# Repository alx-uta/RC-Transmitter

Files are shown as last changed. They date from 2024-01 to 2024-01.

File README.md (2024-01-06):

# RC-Transmitter
This is a custom RC Transmitter that's using ESP32 and Semtech SX1280

Authors:
- Marian Uta
- Alex Heisler

# Project Status - WIP
- [https://microknot.dev/rc-transmitter-project-status/](https://microknot.dev/rc-transmitter-project-status/)

---

# Useful links
- [Build Tutorial](https://microknot.dev/rc-transmitter-build-tutorial-esp32-sx1280/)
- [Wiring Tutorial](https://microknot.dev/rc-transmitter-wiring-tutorial-esp32-sx1280/)
- [Calibration Tutorial](https://microknot.dev/rc-transmitter-calibration-tutorial/)

---

- Required Parts:
  - [3D Files](https://docs.google.com/spreadsheets/d/1K6EamDLu7aNF5GFfuzi9vV8SCz_6HzOA_h1CgVDcLqo/edit?usp=sharing)
  - [PCB](https://docs.google.com/spreadsheets/d/1bTyJoKmJrHec9gnfRhsfcdIJgJ4cUt9kbDGZgcYngUU/edit?usp=sharing)
  - [BOM](https://docs.google.com/spreadsheets/d/1osKjM83mz0m_O5QN-AISYl1IssTSeUwu/edit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)

---
Links:
- [Discord](https://discord.gg/eHyz2aJ6)

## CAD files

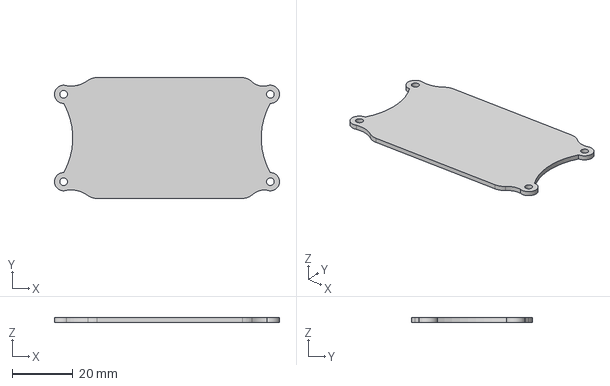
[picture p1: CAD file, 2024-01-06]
3D/CNC_Files/ScreenProtector.step
74.0 x 39.8 x 1.50 mm

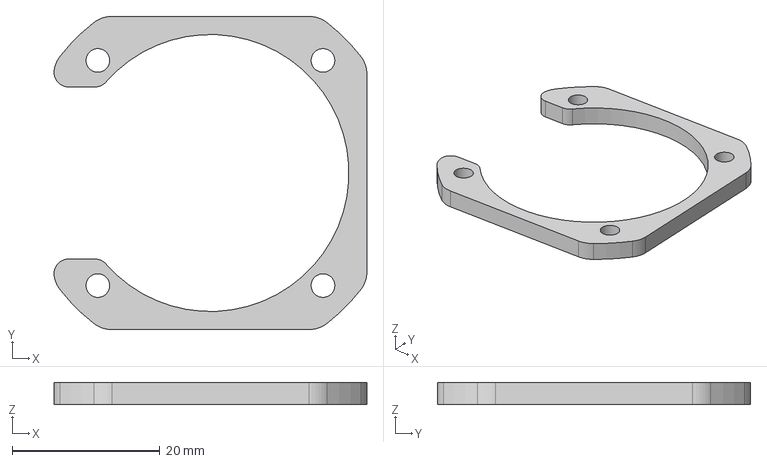
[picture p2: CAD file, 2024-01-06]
3D/STEP/Generic/RotaryEncoderSpacer.step
42.4 x 42.4 x 3.00 mm

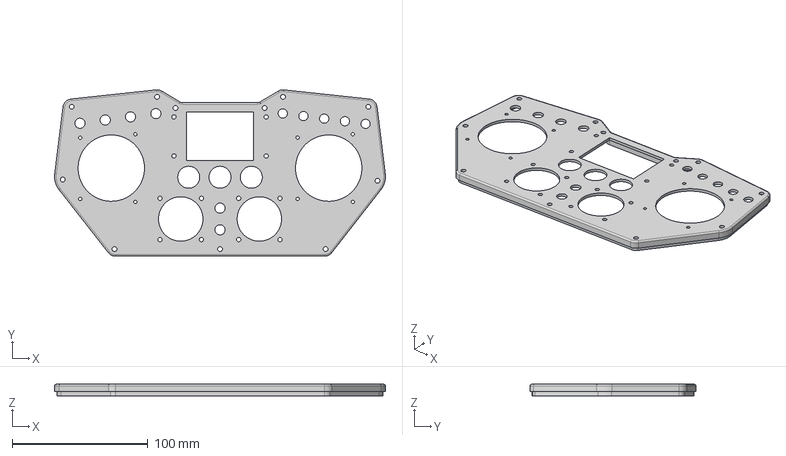
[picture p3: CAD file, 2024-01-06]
3D/STEP/MainBody/Top_Joysticks_AG01.step
244.2 x 122.8 x 8.50 mm

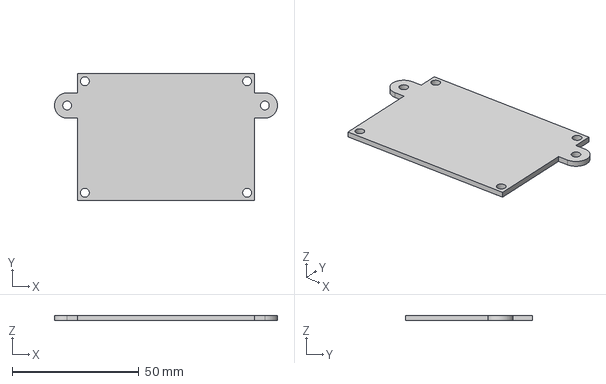
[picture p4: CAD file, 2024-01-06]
3D/STEP/PCB/PCB_Holder.step
88.0 x 50.0 x 2.00 mm

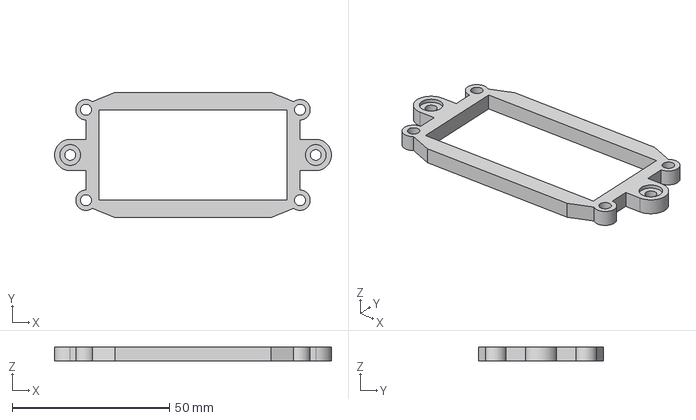
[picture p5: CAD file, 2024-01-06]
3D/STEP/Screen/ScreenHolder.step
88.0 x 39.8 x 4.50 mm

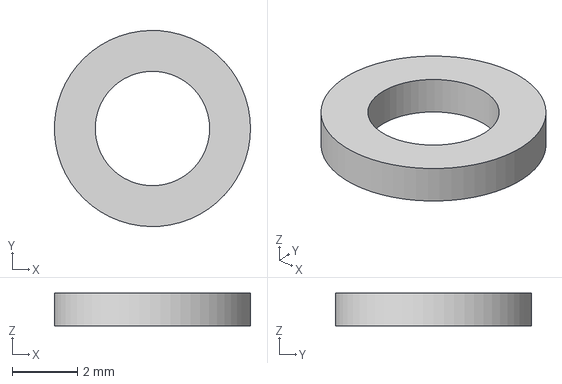
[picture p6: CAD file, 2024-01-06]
3D/STEP/Generic/Spacer.step
6.00 x 6.00 x 1.00 mm

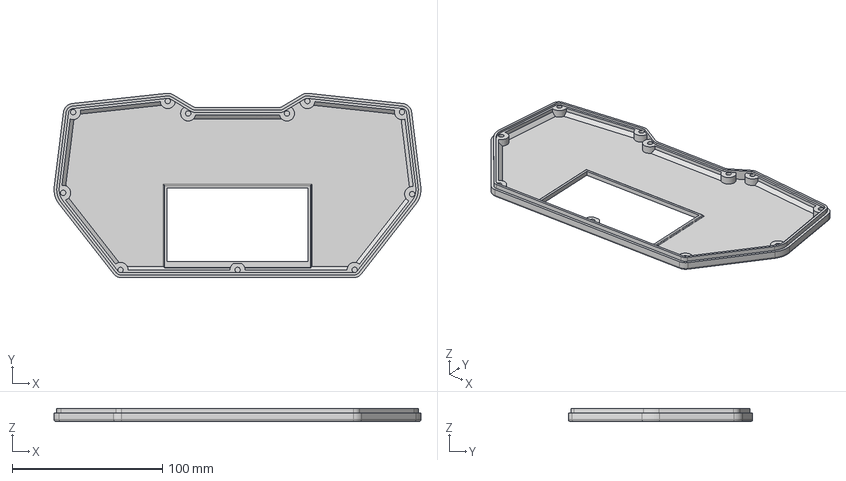
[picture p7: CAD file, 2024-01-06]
3D/STEP/MainBody/Bottom.step
244.2 x 122.8 x 8.50 mm

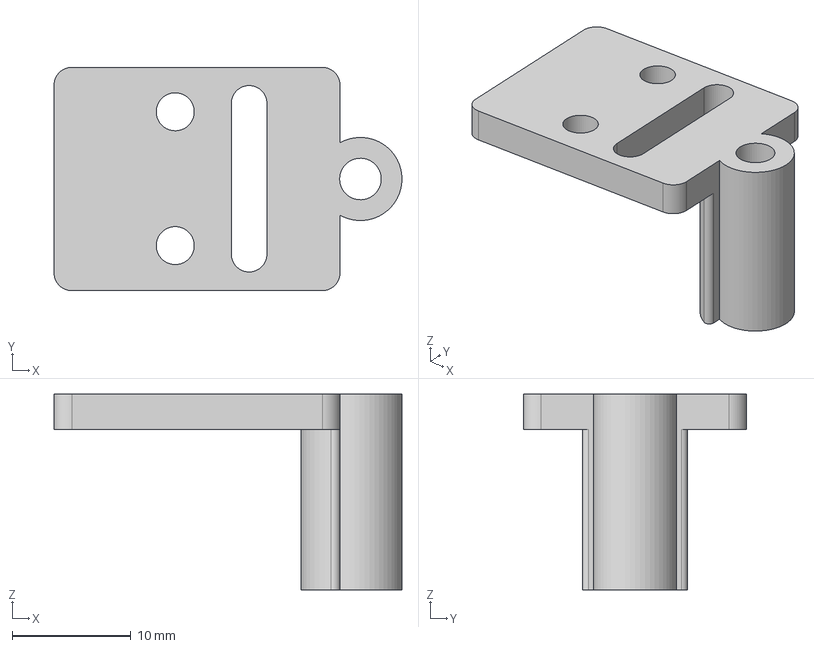
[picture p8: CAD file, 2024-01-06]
3D/STEP/PCB/JoystickAdapterHolder.step
29.3 x 18.8 x 16.5 mm

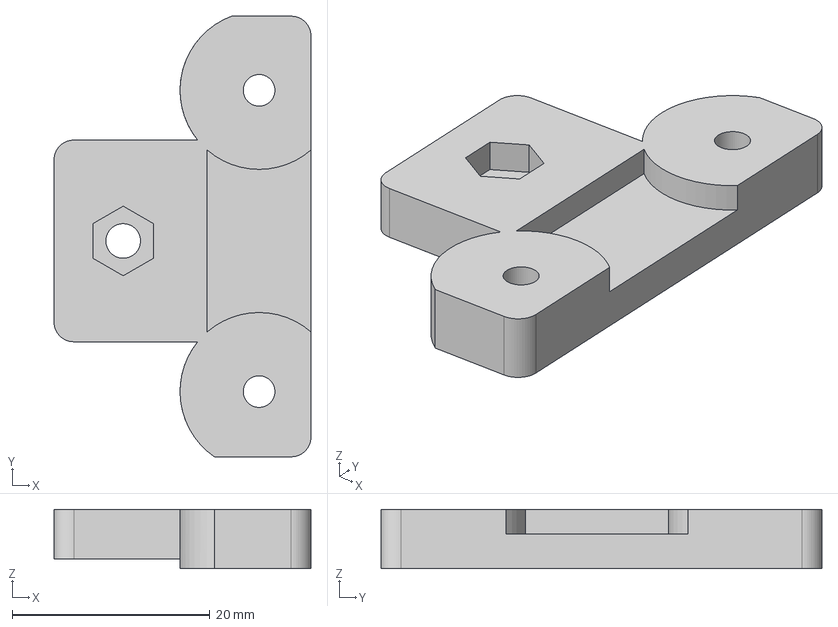
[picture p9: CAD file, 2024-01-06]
3D/STEP/Battery/BatteryHolderConnector.step
26.0 x 44.6 x 6.00 mm

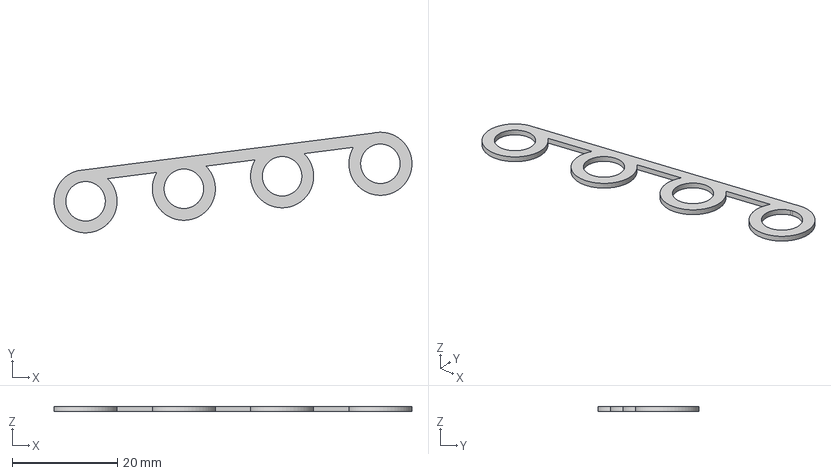
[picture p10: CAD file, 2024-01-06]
3D/STEP/Generic/PotentiometersHolder_4.step
68.0 x 19.1 x 1.00 mm

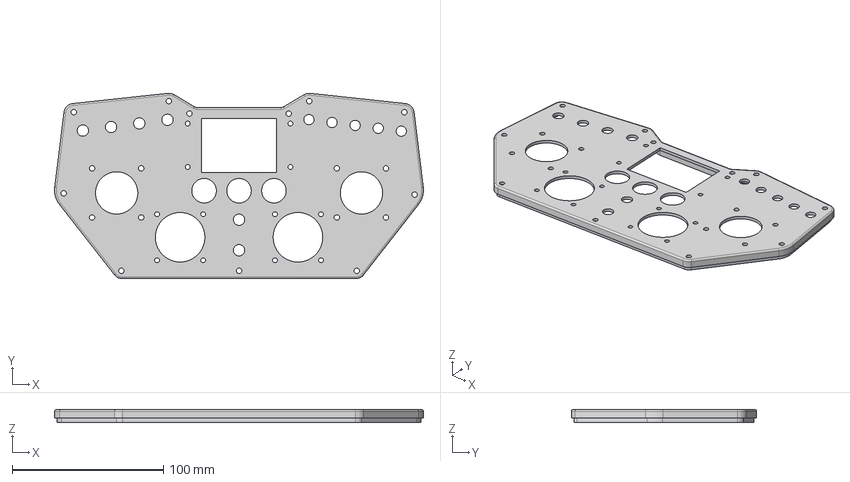
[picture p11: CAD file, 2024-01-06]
3D/STEP/MainBody/Top_Joysticks_JH-D202X.step
244.2 x 122.8 x 8.50 mm

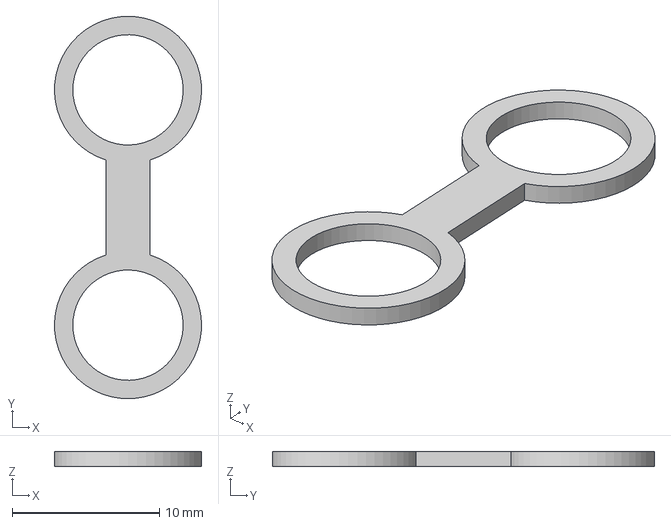
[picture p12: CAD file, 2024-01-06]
3D/STEP/Generic/PotentiometersHolder_2.step
9.99 x 26.0 x 1.00 mm

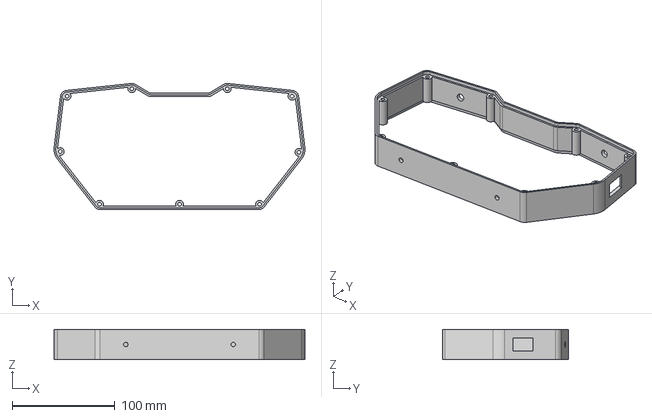
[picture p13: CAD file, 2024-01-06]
3D/STEP/MainBody/Middle.step
244.2 x 122.8 x 29.5 mm

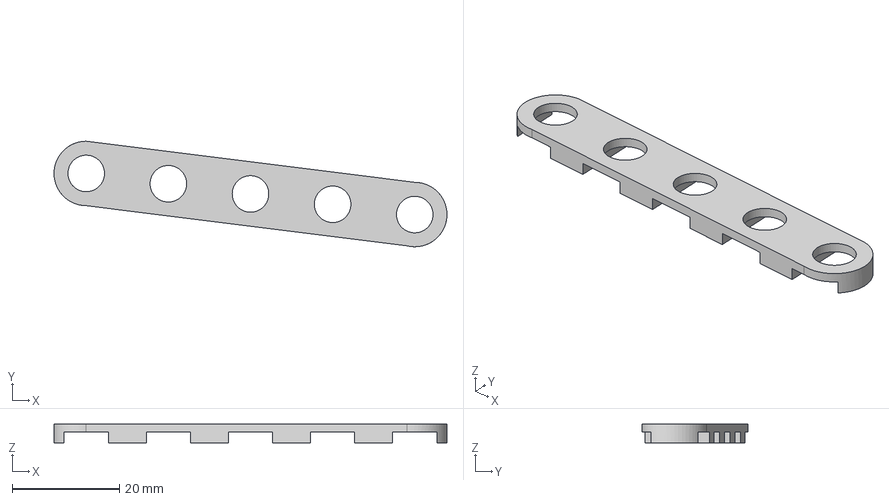
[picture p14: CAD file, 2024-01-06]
3D/STEP/Generic/SwitchesHolder.step
73.1 x 19.7 x 3.50 mm

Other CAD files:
3D/STEP/Battery/BatteryCover.step
3D/STEP/Battery/21700_BatteryHolder.step
3D/STEP/Battery/18650_BatteryHolderSpacer.step
3D/STEP/Battery/18650_BatteryHolder.step
3D/STEP/Battery/21700_BatteryHolderSpacer.step
3D/STL/Battery/18650_BatteryHolder.stl
3D/STL/Battery/18650_BatteryHolderSpacer.stl
3D/STL/Battery/21700_BatteryHolder.stl
3D/STL/Battery/21700_BatteryHolderSpacer.stl
3D/STL/Battery/BatteryCover.stl
3D/STL/Battery/BatteryHolderConnector.stl
3D/STL/Generic/PotentiometersHolder_2.stl
3D/STL/Generic/PotentiometersHolder_4.stl
3D/STL/Generic/RotaryEncoderSpacer.stl
3D/STL/Generic/Spacer.stl
3D/STL/Generic/SwitchesHolder.stl
3D/STL/MainBody/Bottom.stl
3D/STL/MainBody/Middle.stl
3D/STL/MainBody/Top_Joysticks_AG01.stl
3D/STL/MainBody/Top_Joysticks_JH-D202X.stl
3D/STL/PCB/JoystickAdapterHolder.stl
3D/STL/PCB/PCB_Holder.stl
3D/STL/Screen/ScreenHolder.stl

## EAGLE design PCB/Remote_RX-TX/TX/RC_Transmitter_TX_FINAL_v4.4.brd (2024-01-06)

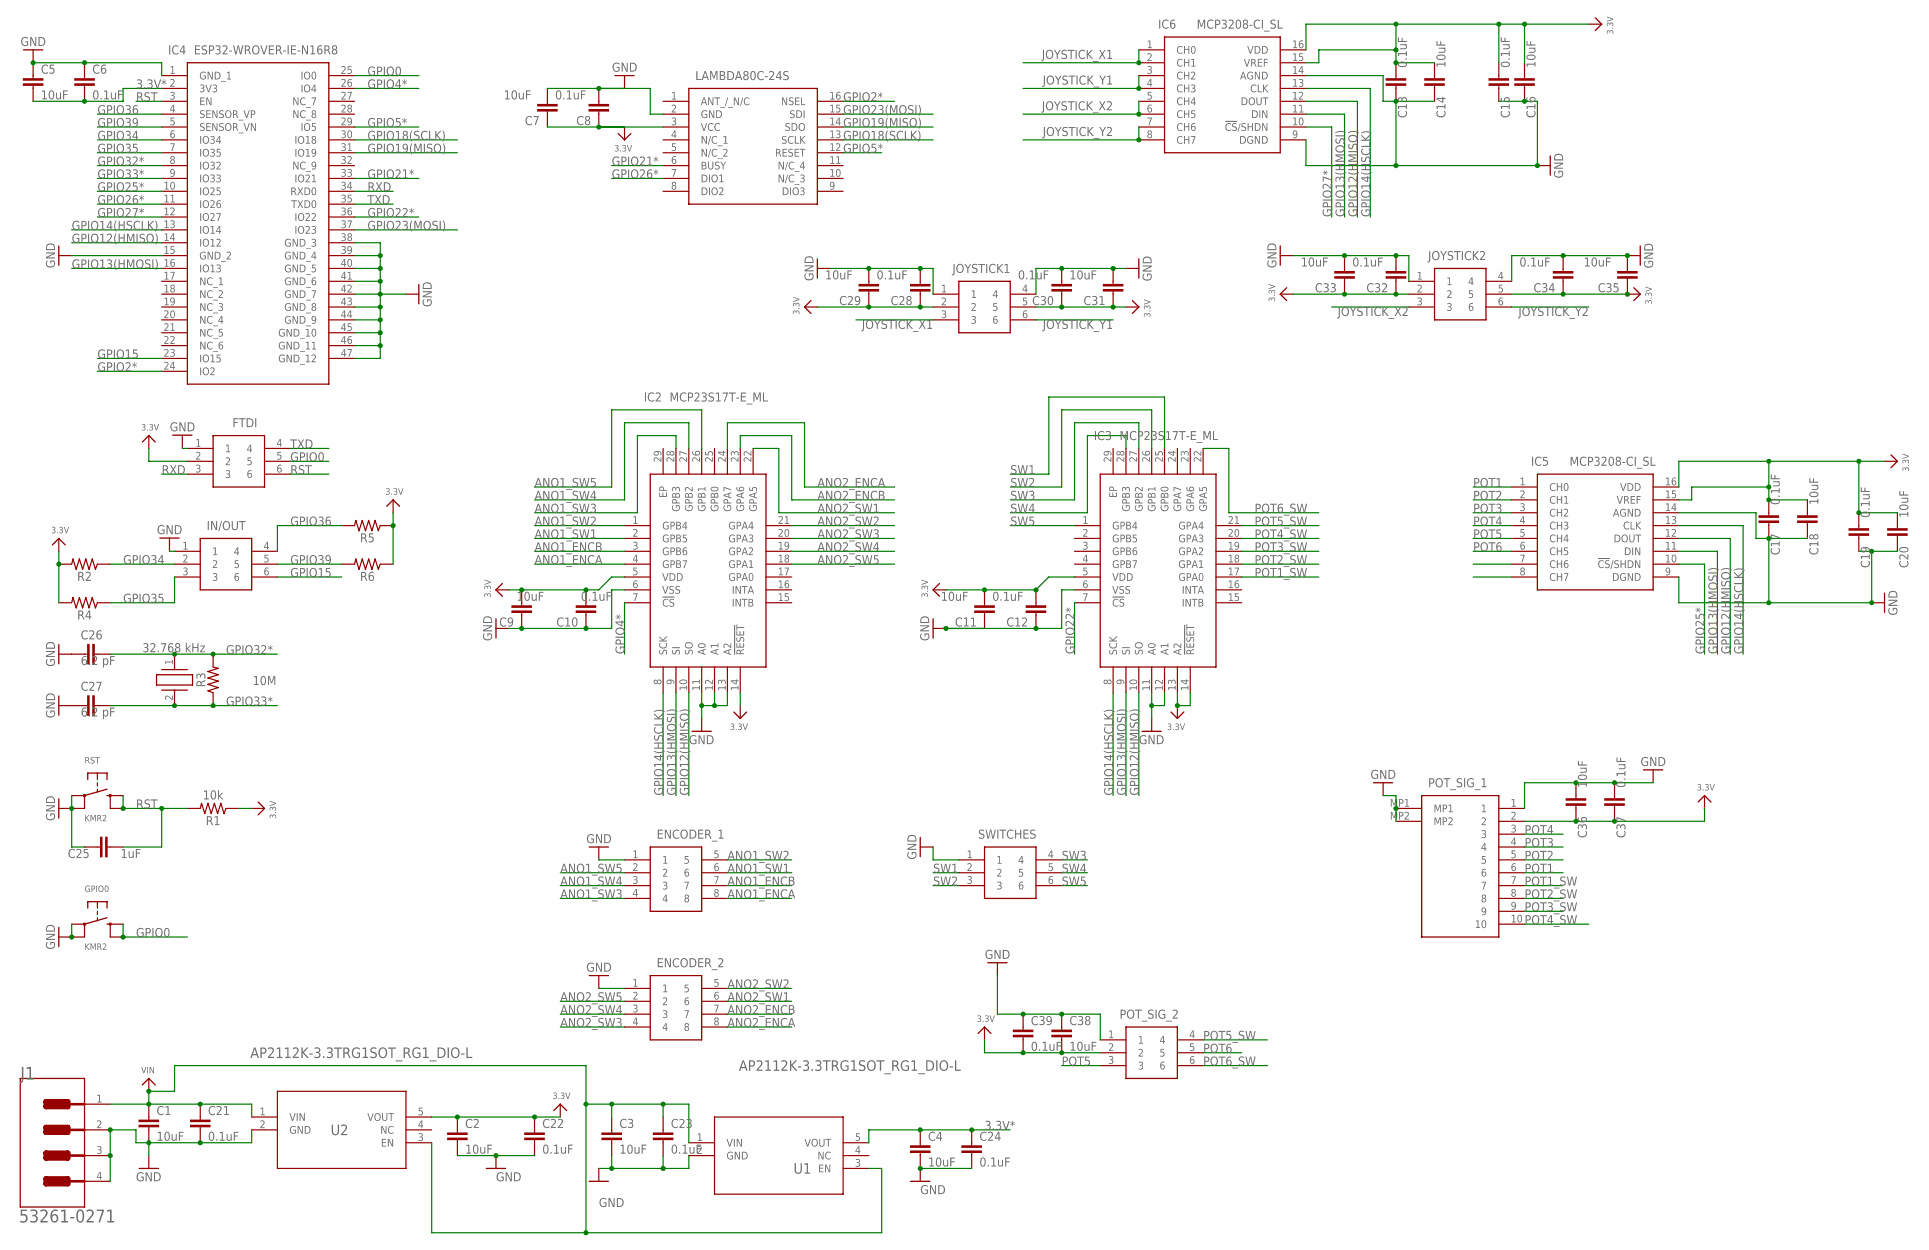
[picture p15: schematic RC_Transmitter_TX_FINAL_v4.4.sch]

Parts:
C1, C2, C3, C4, C5, C7, C9, C11, C14, C16, C18, C20, C29, C31, C33, C35, C36, C38: 10uF; 0805
C6, C8, C10, C12, C13, C15, C17, C19, C21, C22, C23, C24, C28, C30, C32, C34, C37, C39: 0.1uF; 0805
C25: 1uF; 0805
C26, C27: 6.2 pF; 0805
CRYSTAL: 32.768 kHz; ECX327CDX1293
ENCODER_1, ENCODER_2: 0532610871; 53261-0871
FTDI: 0532610671
GPIO0: KMR2; BTN_KMR2_4.6X2.8
IC1: LAMBDA80C-24S; LAMBDA80C24S
IC2, IC3: MCP23S17T-E_ML; QFN65P600X600X100-29N
IC4: ESP32-WROVER-IE-N16R8; ESP32WROVERIEN16R8
IC5, IC6: MCP3208-CI_SL; SOIC127P600X175-16N
IN/OUT: 0532610671
J1: MOLEX_53261-0271MOLEX_53261-0271_0_0; MOLEX_53261-0271_0
JOYSTICK1, JOYSTICK2: 0532610671
POT_SIG_1: 0532611071
POT_SIG_2: 0532610671
R1, R2, R4, R5, R6: 10k; 0603
R3: 10M; 0603
RST: KMR2; BTN_KMR2_4.6X2.8
SWITCHES: 0532610671
U1, U2: AP2112K-3.3TRG1SOT_RG1_DIO-L; SOT_RG1_DIO-L

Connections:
3.3V: C2.1, C7.1, C8.1, C9.2, C10.2, C11.2, C12.2, C13.2, C14.2, C15.2, C16.2, C17.2, C18.2, C19.2, C20.2, C22.1, C28.1, C29.1, C30.1, C31.1, C32.1, C33.1, C34.1, C35.1, C36.1, C37.1, C38.2, C39.2, FTDI.2, IC1.3 (VCC), IC2.5 (VDD), IC2.14 (!RESET), IC3.5 (VDD), IC3.13 (A2), IC3.14 (!RESET), IC5.15 (VREF), IC5.16 (VDD), IC6.15 (VREF), IC6.16 (VDD), JOYSTICK1.2, JOYSTICK1.5, JOYSTICK2.2, JOYSTICK2.5, POT_SIG_1.2, POT_SIG_2.2, R1.1, R2.2, R4.2, R5.1, R6.1, U2.5 (VOUT)
3.3V*: C4.1, C5.2, C6.2, C24.1, IC4.2 (3V3), U1.5 (VOUT)
ANO1_ENCA: ENCODER_1.8, IC2.4 (GPB7)
ANO1_ENCB: ENCODER_1.7, IC2.3 (GPB6)
ANO1_SW1: ENCODER_1.6, IC2.2 (GPB5)
ANO1_SW2: ENCODER_1.5, IC2.1 (GPB4)
ANO1_SW3: ENCODER_1.4, IC2.28 (GPB3)
ANO1_SW4: ENCODER_1.3, IC2.27 (GPB2)
ANO1_SW5: ENCODER_1.2, IC2.26 (GPB1)
ANO2_ENCA: ENCODER_2.8, IC2.24 (GPA7)
ANO2_ENCB: ENCODER_2.7, IC2.23 (GPA6)
ANO2_SW1: ENCODER_2.6, IC2.22 (GPA5)
ANO2_SW2: ENCODER_2.5, IC2.21 (GPA4)
ANO2_SW3: ENCODER_2.4, IC2.20 (GPA3)
ANO2_SW4: ENCODER_2.3, IC2.19 (GPA2)
ANO2_SW5: ENCODER_2.2, IC2.18 (GPA1)
GND: C1.2, C2.2, C3.2, C4.2, C5.1, C6.1, C7.2, C8.2, C9.1, C10.1, C11.1, C12.1, C13.1, C14.1, C15.1, C16.1, C17.1, C18.1, C19.1, C20.1, C21.2, C22.2, C23.2, C24.2, C25.1, C26.1, C27.1, C28.2, C29.2, C30.2, C31.2, C32.2, C33.2, C34.2, C35.2, C36.2, C37.2, C38.1, C39.1, ENCODER_1.1, ENCODER_2.1, FTDI.1, GPIO0.A, GPIO0.A' (P1), IC1.2 (GND), IC2.6 (VSS), IC2.11 (A0), IC2.12 (A1), IC2.13 (A2), IC3.6 (VSS), IC3.11 (A0), IC3.12 (A1), IC4.1 (GND_1), IC4.15 (GND_2), IC4.38 (GND_3), IC4.39 (GND_4), IC4.40 (GND_5), IC4.41 (GND_6), IC4.42 (GND_7), IC4.43 (GND_8), IC4.44 (GND_9), IC4.45 (GND_10), IC4.46 (GND_11), IC4.47 (GND_12), IC5.9 (DGND), IC5.14 (AGND), IC6.9 (DGND), IC6.14 (AGND), IN/OUT.1, J1.2, J1.3 (MNT_1), J1.4 (MNT_2), JOYSTICK1.1, JOYSTICK1.4, JOYSTICK2.1, JOYSTICK2.4, POT_SIG_1.1, POT_SIG_1.MP1, POT_SIG_1.MP2, POT_SIG_2.1, RST.A, RST.A' (P1), SWITCHES.1, U1.2 (GND), U2.2 (GND)
GPIO0: FTDI.5, GPIO0.B (S), GPIO0.B' (S1), IC4.25 (IO0)
GPIO2*: IC1.16 (NSEL), IC4.24 (IO2)
GPIO4*: IC2.7 (!CS), IC4.26 (IO4)
GPIO5*: IC1.12 (RESET), IC4.29 (IO5)
GPIO12(HMISO): IC2.10 (SO), IC3.10 (SO), IC4.14 (IO12), IC5.12 (DOUT), IC6.12 (DOUT)
GPIO13(HMOSI): IC2.9 (SI), IC3.9 (SI), IC4.16 (IO13), IC5.11 (DIN), IC6.11 (DIN)
GPIO14(HSCLK): IC2.8 (SCK), IC3.8 (SCK), IC4.13 (IO14), IC5.13 (CLK), IC6.13 (CLK)
GPIO15: IC4.23 (IO15), IN/OUT.6
GPIO18(SCLK): IC1.13 (SCLK), IC4.30 (IO18)
GPIO19(MISO): IC1.14 (SDO), IC4.31 (IO19)
GPIO21*: IC1.6 (BUSY), IC4.33 (IO21)
GPIO22*: IC3.7 (!CS), IC4.36 (IO22)
GPIO23(MOSI): IC1.15 (SDI), IC4.37 (IO23)
GPIO25*: IC4.10 (IO25), IC5.10 (!CS!/SHDN)
GPIO26*: IC1.7 (DIO1), IC4.11 (IO26)
GPIO27*: IC4.12 (IO27), IC6.10 (!CS!/SHDN)
GPIO32*: C26.2, CRYSTAL.1 (X1), IC4.8 (IO32), R3.2
GPIO33*: C27.2, CRYSTAL.2 (X2), IC4.9 (IO33), R3.1
GPIO34: IC4.6 (IO34), IN/OUT.2, R2.1
GPIO35: IC4.7 (IO35), IN/OUT.3, R4.1
GPIO36: IC4.4 (SENSOR_VP), IN/OUT.4, R5.2
GPIO39: IC4.5 (SENSOR_VN), IN/OUT.5, R6.2
JOYSTICK_X1: IC6.1 (CH0), IC6.2 (CH1), JOYSTICK1.3
JOYSTICK_X2: IC6.5 (CH4), IC6.6 (CH5), JOYSTICK2.3
JOYSTICK_Y1: IC6.3 (CH2), IC6.4 (CH3), JOYSTICK1.6
JOYSTICK_Y2: IC6.7 (CH6), IC6.8 (CH7), JOYSTICK2.6
POT1: IC5.1 (CH0), POT_SIG_1.6
POT1_SW: IC3.17 (GPA0), POT_SIG_1.7
POT2: IC5.2 (CH1), POT_SIG_1.5
POT2_SW: IC3.18 (GPA1), POT_SIG_1.8
POT3: IC5.3 (CH2), POT_SIG_1.4
POT3_SW: IC3.19 (GPA2), POT_SIG_1.9
POT4: IC5.4 (CH3), POT_SIG_1.3
POT4_SW: IC3.20 (GPA3), POT_SIG_1.10
POT5: IC5.5 (CH4), POT_SIG_2.3
POT5_SW: IC3.21 (GPA4), POT_SIG_2.4
POT6: IC5.6 (CH5), POT_SIG_2.5
POT6_SW: IC3.22 (GPA5), POT_SIG_2.6
RST: C25.2, FTDI.6, IC4.3 (EN), R1.2, RST.B (S), RST.B' (S1)
RXD: FTDI.3, IC4.34 (RXD0)
SW1: IC3.25 (GPB0), SWITCHES.2
SW2: IC3.26 (GPB1), SWITCHES.3
SW3: IC3.27 (GPB2), SWITCHES.4
SW4: IC3.28 (GPB3), SWITCHES.5
SW5: IC3.1 (GPB4), SWITCHES.6
TXD: FTDI.4, IC4.35 (TXD0)
VIN: C1.1, C3.1, C21.1, C23.1, J1.1, U1.1 (VIN), U1.3 (EN), U2.1 (VIN), U2.3 (EN)

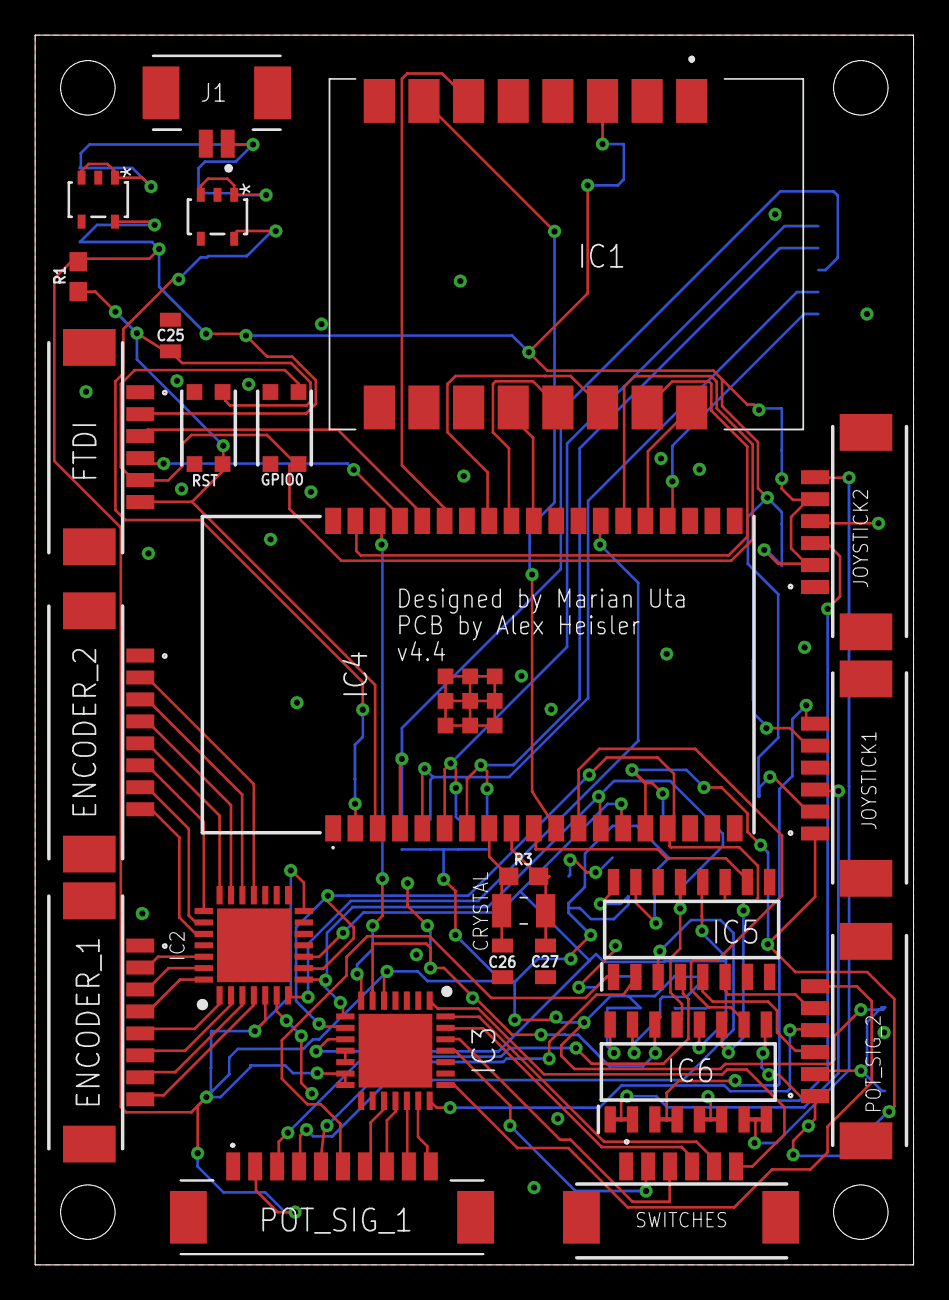
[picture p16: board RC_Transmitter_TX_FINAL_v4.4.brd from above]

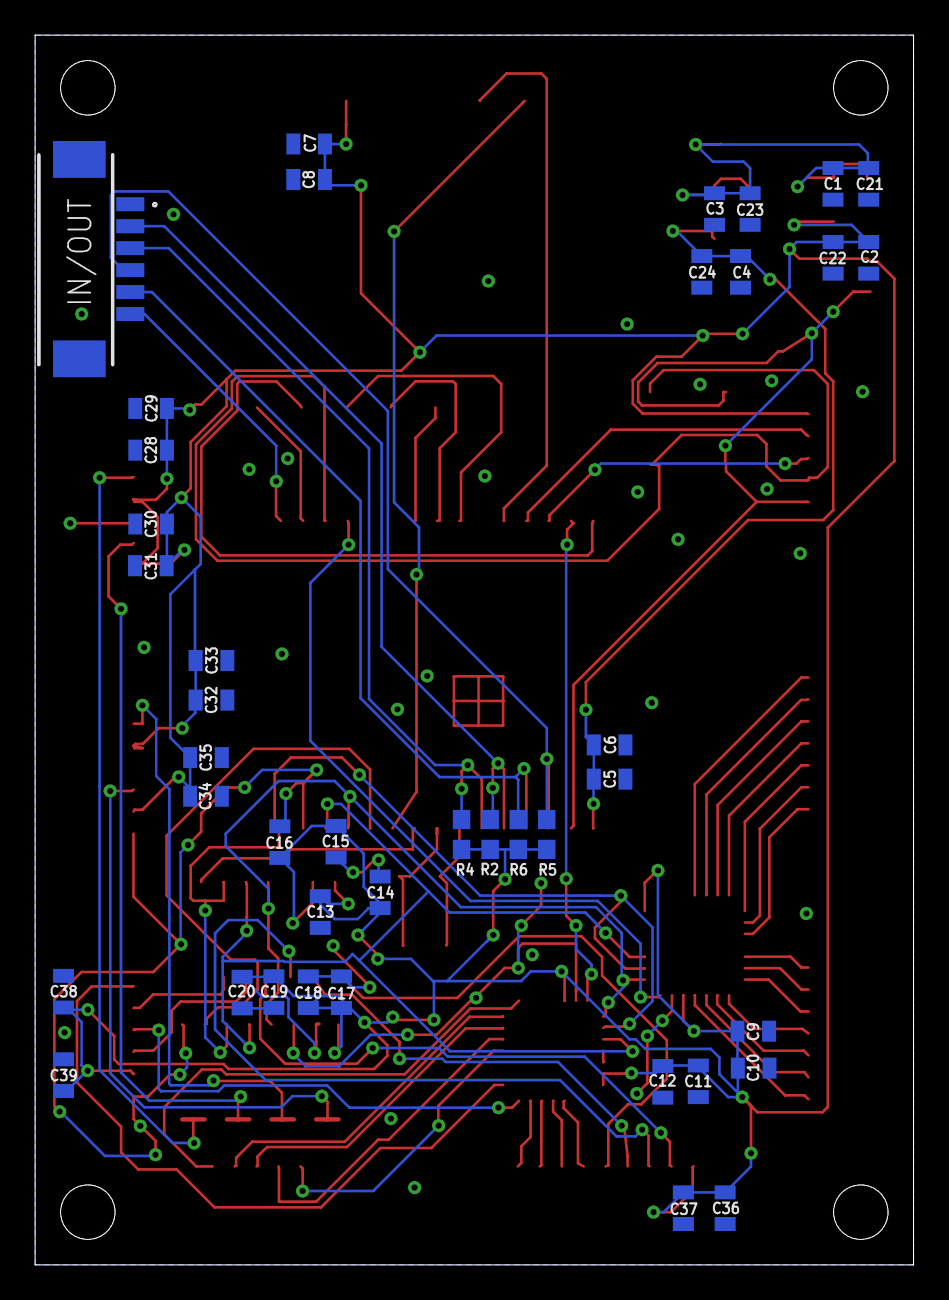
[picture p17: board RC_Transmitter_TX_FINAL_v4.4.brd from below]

Board: 2 copper layers, 50.0 x 70.0 mm, 66 parts (41 on the bottom side), 64 nets.

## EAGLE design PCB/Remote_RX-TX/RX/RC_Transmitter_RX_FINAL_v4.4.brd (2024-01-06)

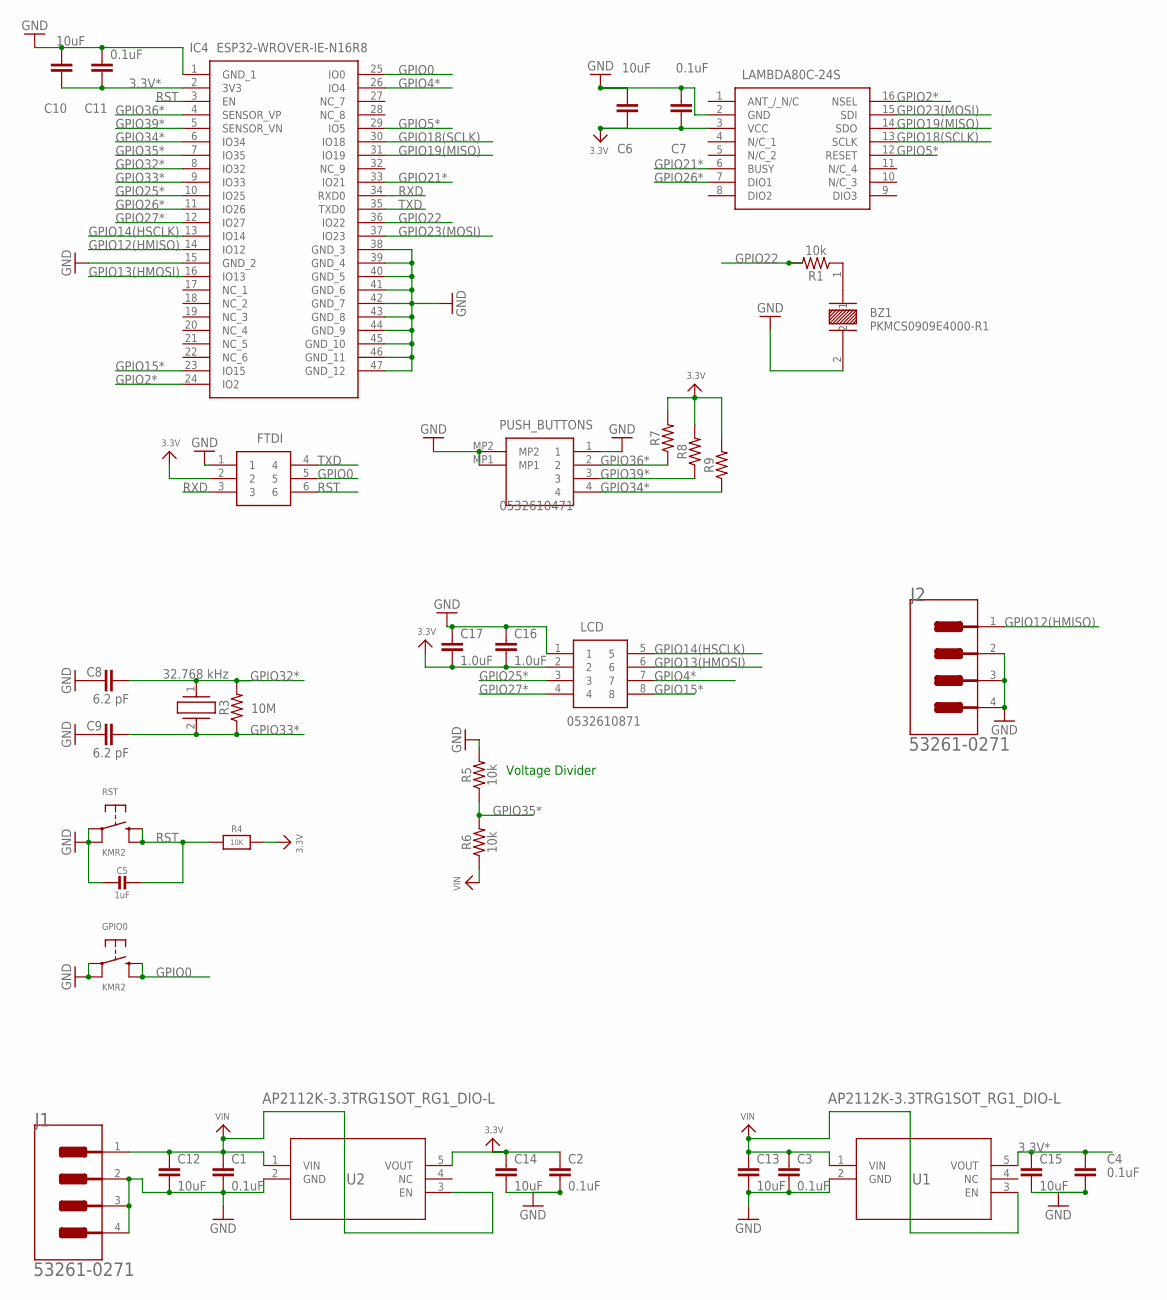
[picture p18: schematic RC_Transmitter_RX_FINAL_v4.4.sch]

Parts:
BZ1: PKMCS0909E4000-R1
C1, C2, C3, C4, C7, C11: 0.1uF; 0805
C5: 1uF; 0805-NO
C6, C10, C12, C13, C14, C15: 10uF; 0805
C8, C9: 6.2 pF; CAPC2012X110
C16, C17: 1.0uF; 0805
CRYSTAL: 32.768 kHz; ECX327CDX1293
FTDI: 0532610671
GPIO0: KMR2; BTN_KMR2_4.6X2.8
IC1: LAMBDA80C-24S; LAMBDA80C24S
IC4: ESP32-WROVER-IE-N16R8; ESP32WROVERIEN16R8
J1, J2: MOLEX_53261-0271MOLEX_53261-0271_0_0; MOLEX_53261-0271_0
LCD: 0532610871; 53261-0871
PUSH_BUTTONS: 0532610471
R1, R5, R6: 10k; 0603
R3: 10M; 0603
R4: 10K; _0805
R7, R8, R9: 0; 0603
RST: KMR2; BTN_KMR2_4.6X2.8
U1, U2: AP2112K-3.3TRG1SOT_RG1_DIO-L; SOT_RG1_DIO-L

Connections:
3.3V: C2.1, C6.1, C7.1, C14.1, C16.2, C17.2, FTDI.2, IC1.3 (VCC), LCD.2, R4.2, R7.2, R8.2, R9.2, U2.5 (VOUT)
3.3V*: C4.1, C10.1, C11.1, C15.1, IC4.2 (3V3), U1.5 (VOUT)
GND: BZ1.2, C1.2, C2.2, C3.2, C4.2, C5.2, C6.2, C7.2, C8.1, C9.1, C10.2, C11.2, C12.2, C13.2, C14.2, C15.2, C16.1, C17.1, FTDI.1, GPIO0.A, GPIO0.A' (P1), IC1.2 (GND), IC4.1 (GND_1), IC4.15 (GND_2), IC4.38 (GND_3), IC4.39 (GND_4), IC4.40 (GND_5), IC4.41 (GND_6), IC4.42 (GND_7), IC4.43 (GND_8), IC4.44 (GND_9), IC4.45 (GND_10), IC4.46 (GND_11), IC4.47 (GND_12), J1.2, J1.3 (MNT_1), J1.4 (MNT_2), J2.2, J2.3 (MNT_1), J2.4 (MNT_2), LCD.1, PUSH_BUTTONS.1, PUSH_BUTTONS.MP1, PUSH_BUTTONS.MP2, R5.2, RST.A, RST.A' (P1), U1.2 (GND), U2.2 (GND)
GPIO0: FTDI.5, GPIO0.B (S), GPIO0.B' (S1), IC4.25 (IO0)
GPIO2*: IC1.16 (NSEL), IC4.24 (IO2)
GPIO4*: IC4.26 (IO4), LCD.7
GPIO5*: IC1.12 (RESET), IC4.29 (IO5)
GPIO12(HMISO): IC4.14 (IO12), J2.1
GPIO13(HMOSI): IC4.16 (IO13), LCD.6
GPIO14(HSCLK): IC4.13 (IO14), LCD.5
GPIO15*: IC4.23 (IO15), LCD.8
GPIO18(SCLK): IC1.13 (SCLK), IC4.30 (IO18)
GPIO19(MISO): IC1.14 (SDO), IC4.31 (IO19)
GPIO21*: IC1.6 (BUSY), IC4.33 (IO21)
GPIO22: IC4.36 (IO22), R1.2
GPIO23(MOSI): IC1.15 (SDI), IC4.37 (IO23)
GPIO25*: IC4.10 (IO25), LCD.3
GPIO26*: IC1.7 (DIO1), IC4.11 (IO26)
GPIO27*: IC4.12 (IO27), LCD.4
GPIO32*: C8.2, CRYSTAL.1 (X1), IC4.8 (IO32), R3.2
GPIO33*: C9.2, CRYSTAL.2 (X2), IC4.9 (IO33), R3.1
GPIO34*: IC4.6 (IO34), PUSH_BUTTONS.4, R9.1
GPIO35*: IC4.7 (IO35), R5.1, R6.2
GPIO36*: IC4.4 (SENSOR_VP), PUSH_BUTTONS.2, R7.1
GPIO39*: IC4.5 (SENSOR_VN), PUSH_BUTTONS.3, R8.1
unnamed: BZ1.1, R1.1
RST: C5.1, FTDI.6, IC4.3 (EN), R4.1, RST.B (S), RST.B' (S1)
RXD: FTDI.3, IC4.34 (RXD0)
TXD: FTDI.4, IC4.35 (TXD0)
VIN: C1.1, C3.1, C12.1, C13.1, J1.1, R6.1, U1.1 (VIN), U1.3 (EN), U2.1 (VIN), U2.3 (EN)

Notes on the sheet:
Voltage Divider

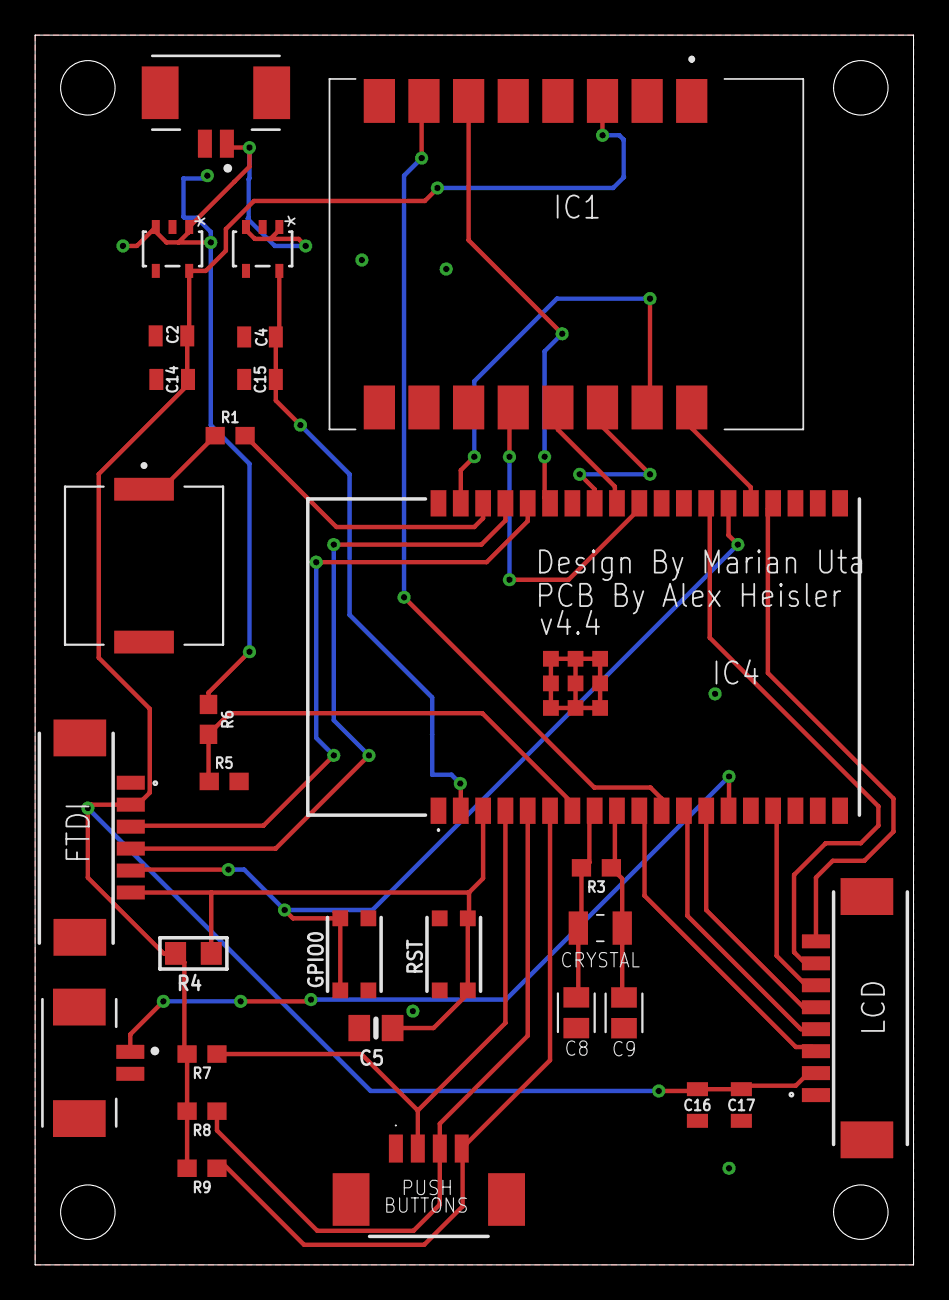
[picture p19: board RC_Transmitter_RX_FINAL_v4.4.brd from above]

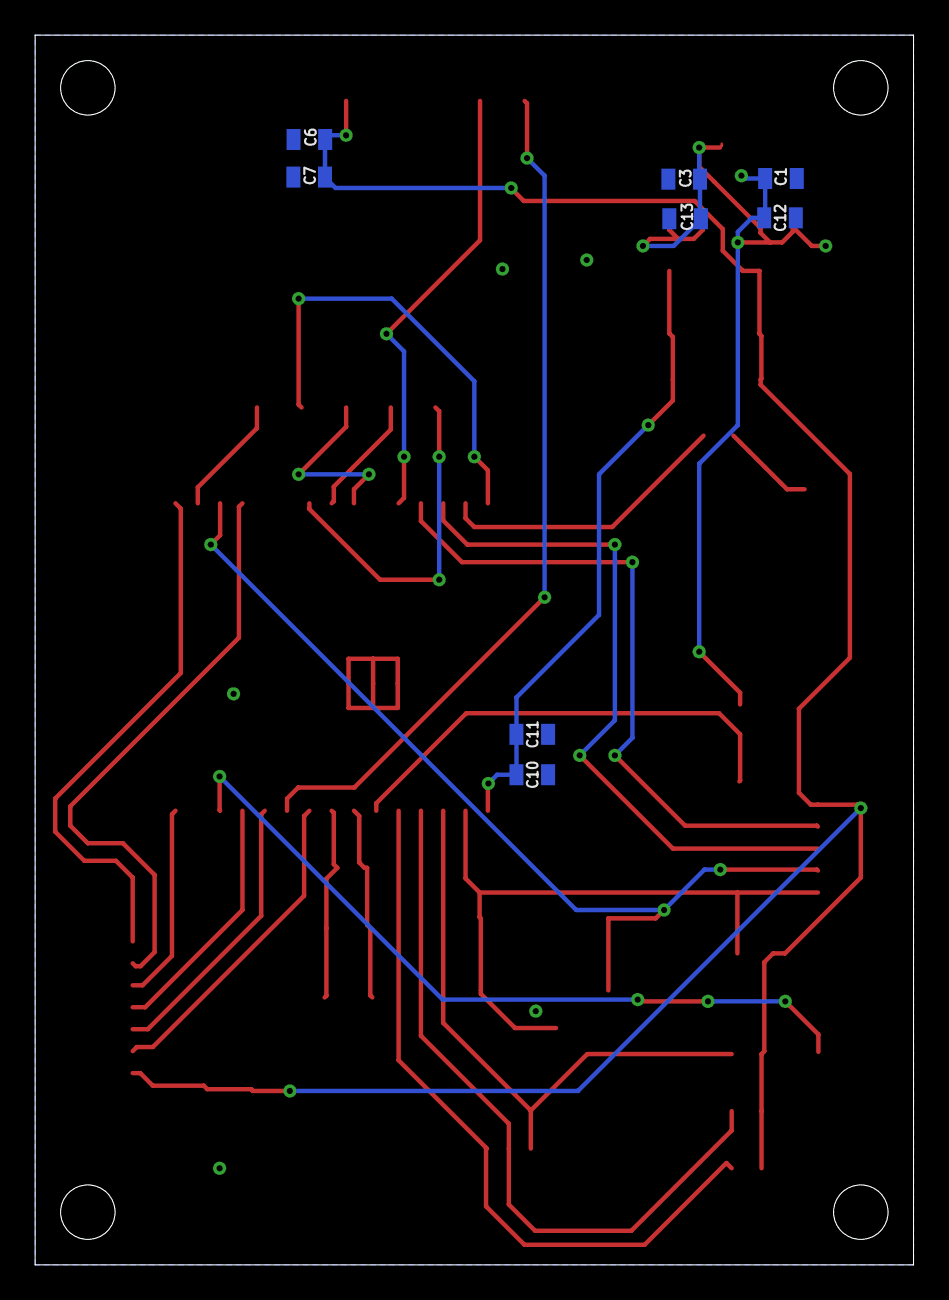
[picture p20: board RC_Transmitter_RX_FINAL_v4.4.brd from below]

Board: 2 copper layers, 50.0 x 70.0 mm, 38 parts (8 on the bottom side), 30 nets.

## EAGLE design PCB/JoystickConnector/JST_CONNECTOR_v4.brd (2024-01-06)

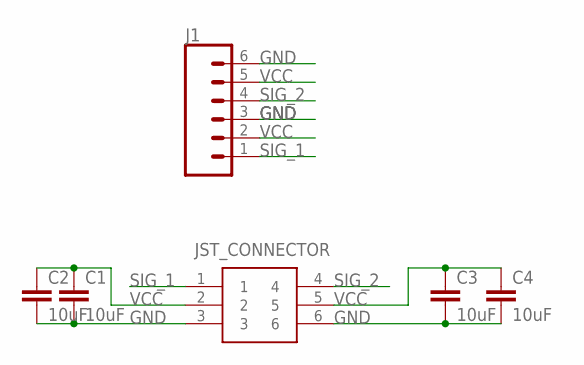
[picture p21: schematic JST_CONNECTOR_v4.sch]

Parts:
C1, C2, C3, C4: 10uF; 0805
J1: CONN_06SILK_FEMALE_PTH; 1X06
JST_CONNECTOR: 0532610671

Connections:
GND: C1.2, C2.2, C3.2, C4.2, J1.3, J1.6, JST_CONNECTOR.3, JST_CONNECTOR.6
SIG_1: J1.1, JST_CONNECTOR.1
SIG_2: J1.4, JST_CONNECTOR.4
VCC: C1.1, C2.1, C3.1, C4.1, J1.2, J1.5, JST_CONNECTOR.2, JST_CONNECTOR.5

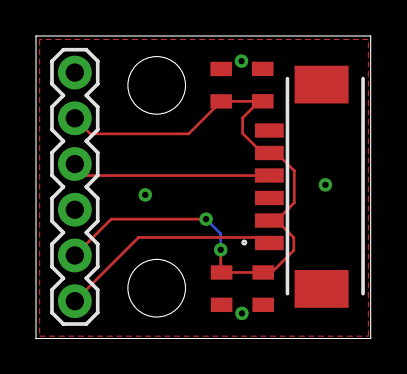
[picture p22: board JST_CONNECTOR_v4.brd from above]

Board: 2 copper layers, 18.6 x 16.8 mm, 6 parts (0 on the bottom side), 4 nets.

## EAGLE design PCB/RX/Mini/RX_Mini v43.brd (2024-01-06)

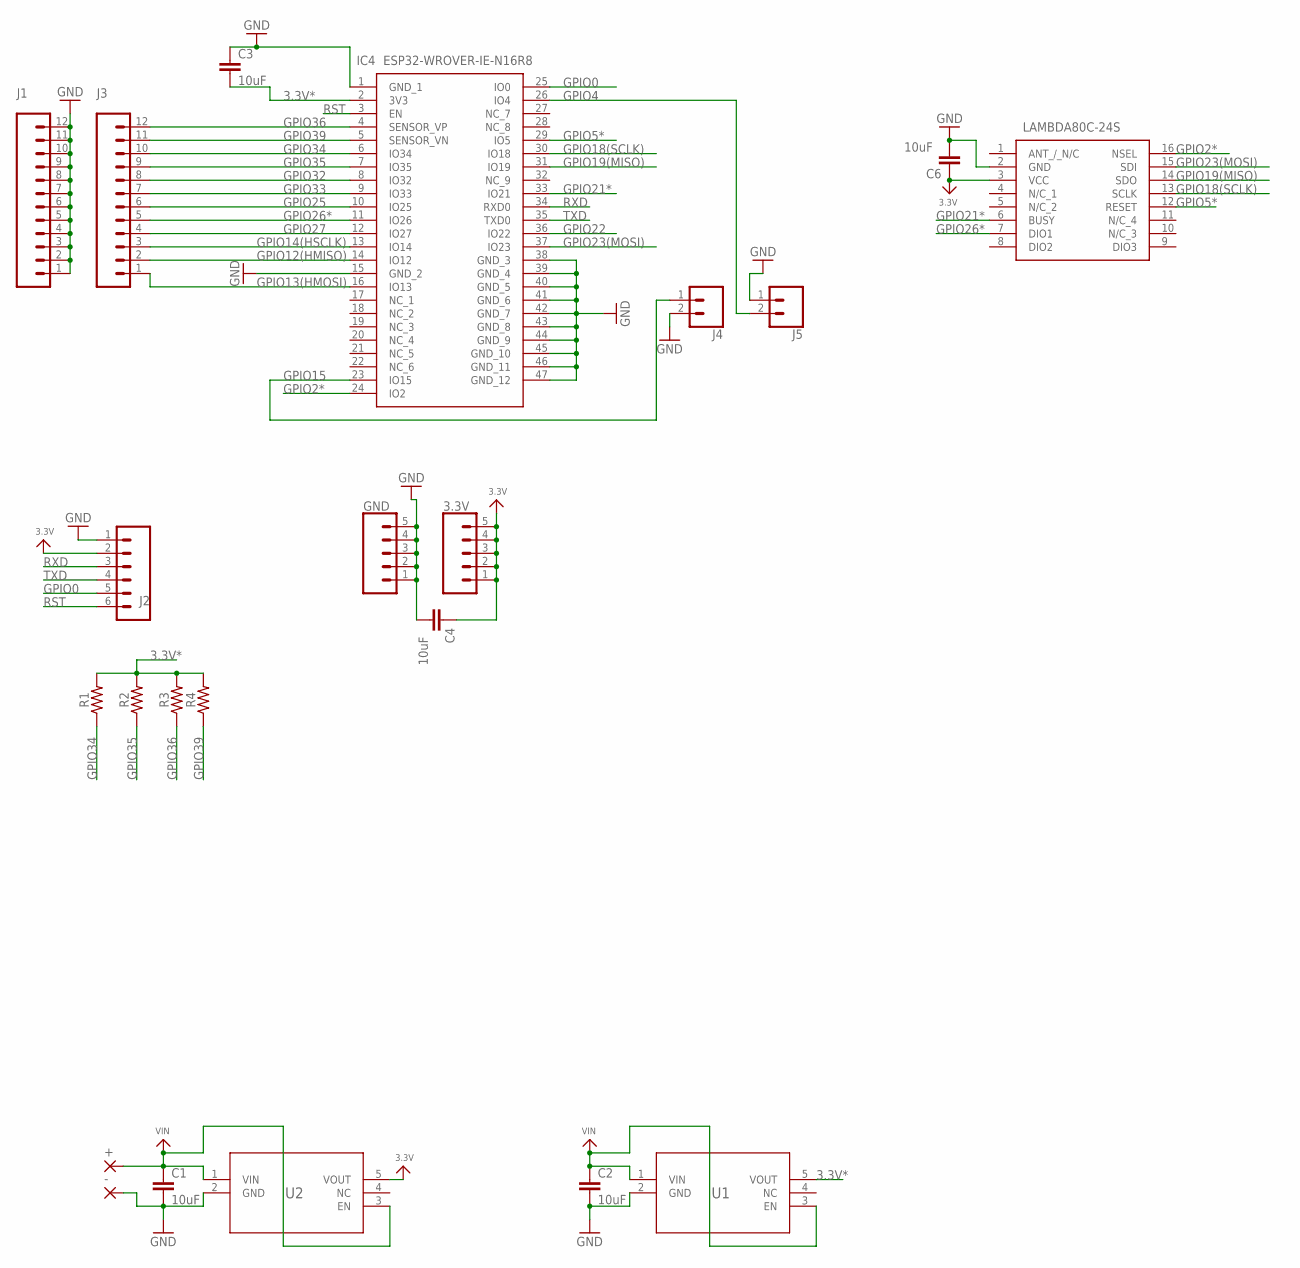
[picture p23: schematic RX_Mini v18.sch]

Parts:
3.3V: CONN_05; 1X05
+: 2,15/1,0
-: 2,15/1,0
C1, C2, C3, C4, C6: 10uF; 0805
GND: CONN_05; 1X05
IC1: LAMBDA80C-24S; LAMBDA80C24S
IC4: ESP32-WROVER-IE-N16R8; ESP32WROVERIEN16R8
J1, J3: CONN_12; 1X12
J2: CONN_06NO_SILK_NO_POP; 1X06_NO_SILK
J4, J5: CONN_02; 1X02
R1, R2, R3, R4: 0; 0603
U1, U2: AP2112K-3.3TRG1SOT_RG1_DIO-L; SOT_RG1_DIO-L

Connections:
3.3V: 3.3V.1, 3.3V.2, 3.3V.3, 3.3V.4, 3.3V.5, C4.1, C6.1, IC1.3 (VCC), J2.2, U2.5 (VOUT)
3.3V*: C3.2, IC4.2 (3V3), R1.2, R2.2, R3.2, R4.2, U1.5 (VOUT)
GND: -.1, C1.2, C2.2, C3.1, C4.2, C6.2, GND.1, GND.2, GND.3, GND.4, GND.5, IC1.2 (GND), IC4.1 (GND_1), IC4.15 (GND_2), IC4.38 (GND_3), IC4.39 (GND_4), IC4.40 (GND_5), IC4.41 (GND_6), IC4.42 (GND_7), IC4.43 (GND_8), IC4.44 (GND_9), IC4.45 (GND_10), IC4.46 (GND_11), IC4.47 (GND_12), J1.1, J1.2, J1.3, J1.4, J1.5, J1.6, J1.7, J1.8, J1.9, J1.10, J1.11, J1.12, J2.1, J4.2, J5.1, U1.2 (GND), U2.2 (GND)
GPIO0: IC4.25 (IO0), J2.5
GPIO2*: IC1.16 (NSEL), IC4.24 (IO2)
GPIO4: IC4.26 (IO4), J5.2
GPIO5*: IC1.12 (RESET), IC4.29 (IO5)
GPIO12(HMISO): IC4.14 (IO12), J3.2
GPIO13(HMOSI): IC4.16 (IO13), J3.1
GPIO14(HSCLK): IC4.13 (IO14), J3.3
GPIO15: IC4.23 (IO15), J4.1
GPIO18(SCLK): IC1.13 (SCLK), IC4.30 (IO18)
GPIO19(MISO): IC1.14 (SDO), IC4.31 (IO19)
GPIO21*: IC1.6 (BUSY), IC4.33 (IO21)
GPIO22: IC4.36 (IO22)
GPIO23(MOSI): IC1.15 (SDI), IC4.37 (IO23)
GPIO25: IC4.10 (IO25), J3.6
GPIO26*: IC1.7 (DIO1), IC4.11 (IO26), J3.5
GPIO27: IC4.12 (IO27), J3.4
GPIO32: IC4.8 (IO32), J3.8
GPIO33: IC4.9 (IO33), J3.7
GPIO34: IC4.6 (IO34), J3.10, R1.1
GPIO35: IC4.7 (IO35), J3.9, R2.1
GPIO36: IC4.4 (SENSOR_VP), J3.12, R3.1
GPIO39: IC4.5 (SENSOR_VN), J3.11, R4.1
RST: IC4.3 (EN), J2.6
RXD: IC4.34 (RXD0), J2.3
TXD: IC4.35 (TXD0), J2.4
VIN: +.1, C1.1, C2.1, U1.1 (VIN), U1.3 (EN), U2.1 (VIN), U2.3 (EN)

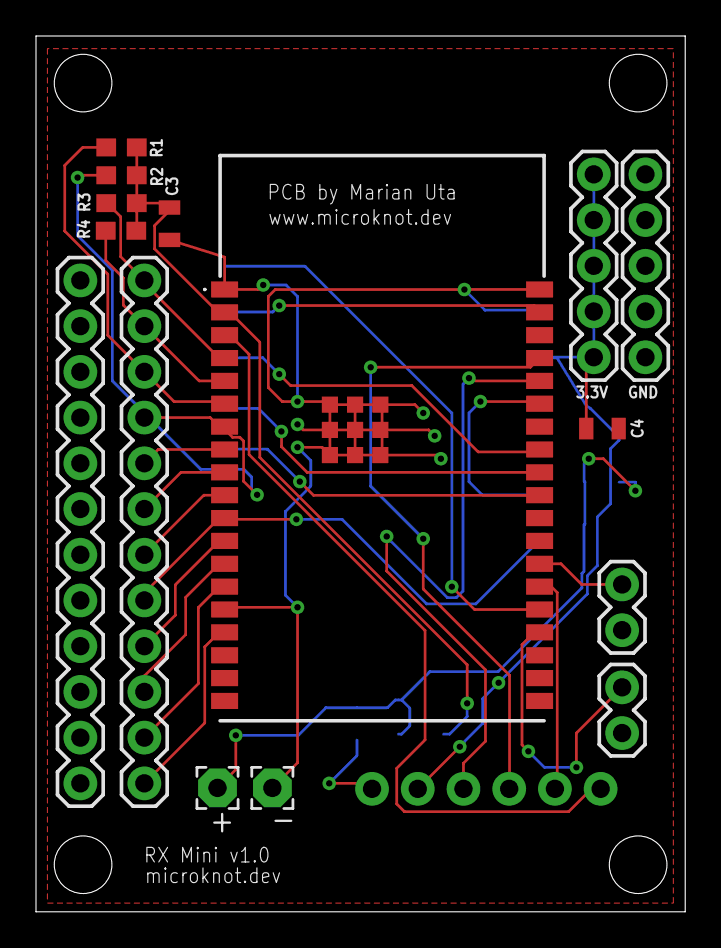
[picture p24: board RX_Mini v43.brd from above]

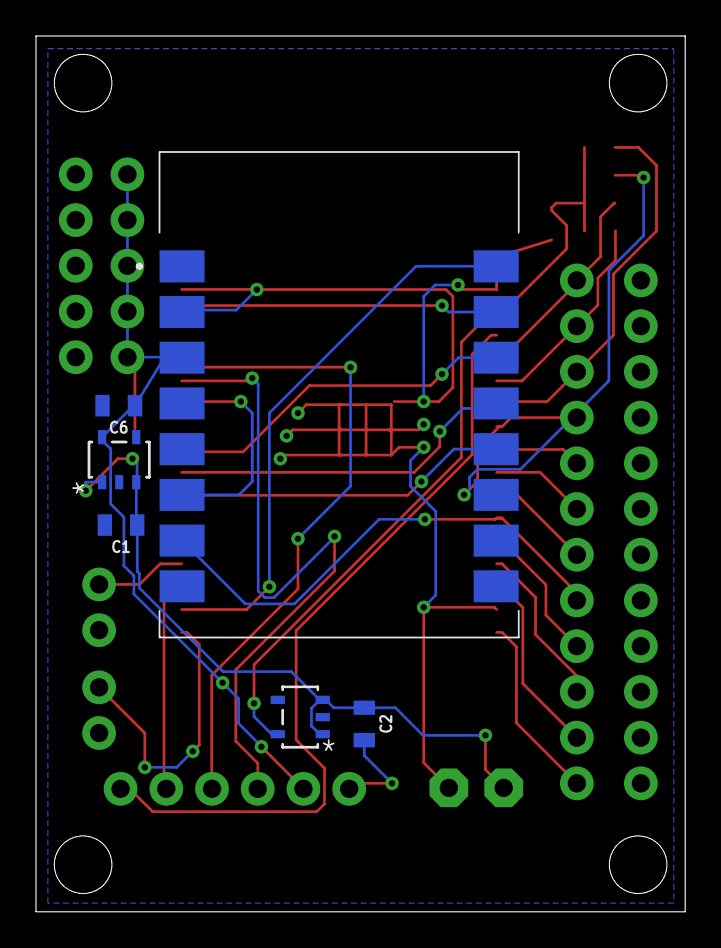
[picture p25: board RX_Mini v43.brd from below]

Board: 2 copper layers, 36.1 x 48.7 mm, 22 parts (6 on the bottom side), 28 nets.

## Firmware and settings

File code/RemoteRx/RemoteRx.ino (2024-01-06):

/**
 * RC Transmitter – ESP32 / SX1280
 * https://github.com/alx-uta/RC-Transmitter
 * 
 * Alex Uta
 * microknot.dev
 */

// ESP32 specific files
#include "soc/timer_group_struct.h"
#include "soc/timer_group_reg.h"

// User Custom Config
#include "user_config.hpp"

// Libraries
#include <TFT_eSPI.h>
#include <SPI.h>
#include <RadioLib.h>

// Custom Files
#include "src/rx/rx.hpp"
#include "src/tft/widgets/display_number/display_number.hpp"
#include "src/tft/widgets/vertical_slider/vertical_slider.hpp"
#include "src/tft/widgets/horizontal_slider/horizontal_slider.hpp"
#include "src/tft/widgets/switch/switch.hpp"
#include "src/tft/widgets/rotary_encoder/rotary_encoder.hpp"
#include "src/tft/widgets/battery_icon/battery_icon.hpp"

// Init and other files
#include "src/init.hpp"
#include "src/setup.hpp"

/**
* We'll use core:0 for TFT update and RX hopping
*/
void func_updateTFT( void * pvParameters ){
    while(true){
        // TFT Update
        _RX.updateTftRemoteTX();

        // Battery check
        _RX.readBatteryPercentage(
            BATTERY_MIN, BATTERY_MAX
        );

        /**
         * Radio Hopping
         */
        rxHopping();
  
        feedTheDog();
    }
}

/**
 * We'll use core:1 to receive the data
 */
void func_txReceiveData( void * pvParameters ){
    while(true){
        /**
         * Receive the data
         */
        receiveData();

        /**
         * Feed the dog
         */
        feedTheDog();
    }
}

void setup() {
    #if ENABLE_SERIAL_PRINT
        Serial.begin(115200);
    #endif

    /**
     * TFT setup
     */
    tft_setup();

    /**
     * SX1280 setup
     */
    SX1280_setup();

    xTaskCreatePinnedToCore(
        func_txReceiveData,
        "task_txReceiveData",
        100 * 1024,
        NULL,
        20,
        &task_txReceiveData,
        taskCore1
    );

    xTaskCreatePinnedToCore(
        func_updateTFT,
        "task_updateTFT",
        100 * 1024,
        NULL,
        19,
        &task_updateTFT,
        taskCore2
    );

}


void loop() {
}

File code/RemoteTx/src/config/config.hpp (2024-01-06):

/**
 * RC Transmitter – ESP32 / SX1280
 * https://github.com/alx-uta/RC-Transmitter
 * 
 * Alex Uta
 * microknot.dev
 */

#ifndef CONFIG_HPP
#define CONFIG_HPP

#include "Arduino.h"

class Config {
	public:
		Config(
            // Joystick General
            uint8_t joystick_default_value,
            uint8_t joystick_min_out,
            uint8_t joystick_max_out,

            // Left Joystick
            uint8_t left_joystick_drift_value_x,
            int left_joystick_min_value_x,
            int left_joystick_max_value_x,
            int left_joystick_middle_value_x,

            uint8_t left_joystick_drift_value_y,
            int left_joystick_min_value_y,
            int left_joystick_max_value_y,
            int left_joystick_middle_value_y,

            // Right Joystick
            uint8_t right_joystick_drift_value_x,
            int right_joystick_min_value_x,
            int right_joystick_max_value_x,
            int right_joystick_middle_value_x,

            uint8_t right_joystick_drift_value_y,
            int right_joystick_min_value_y,
            int right_joystick_max_value_y,
            int right_joystick_middle_value_y,

            // Potentiometers
            uint8_t pot_drift_value,
            uint8_t pot_min,
            int pot_max,
            uint8_t pot_out_min,
            uint8_t pot_out_max
        );
        /**
         * Generic Pinout
         */
        uint8_t SCK_PIN     = 14;
        uint8_t MISO_PIN    = 12;
        uint8_t MOSI_PIN    = 13;

        /**
         * SX1280 Init
         */
        uint8_t SX1280_NSS  = 2;
        uint8_t SX1280_DI01 = 26;
        uint8_t SX1280_NRST = 5;
        uint8_t SX1280_BUSY = 21;

        /**
         * MCP23S17T
         */
        uint8_t MCP23S17T_CS_PIN_0  = 22;
        uint8_t MCP23S17T_ADDR_0    = 0x24;

        uint8_t MCP23S17T_CS_PIN_1 = 4;
        uint8_t MCP23S17T_ADDR_1 = 0x20;

        /**
         * MCP3208
         */
        uint8_t MCP3208_CS_PIN_0 = 25;
        uint8_t MCP3208_CS_PIN_1 = 27;

        // Switch Button
        uint8_t button_switch_1 = 0;
        uint8_t button_switch_2 = 1;
        uint8_t button_switch_3 = 2;
        uint8_t button_switch_4 = 3;
        uint8_t button_switch_5 = 4;

        // Pot Switch Button
        uint8_t button_switch_pot_1 = 8;
        uint8_t button_switch_pot_2 = 9;
        uint8_t button_switch_pot_3 = 10;
        uint8_t button_switch_pot_4 = 11;
        uint8_t button_switch_pot_5 = 12;
        uint8_t button_switch_pot_6 = 13;

        // ANO Rotary Encoder 1
        uint8_t rotary_encoder_1_left =   1;
        uint8_t rotary_encoder_1_up =     2;
        uint8_t rotary_encoder_1_right =  3;
        uint8_t rotary_encoder_1_down =   4;
        uint8_t rotary_encoder_1_center = 5;
        uint8_t rotary_encoder_1_enc_a =  7;
        uint8_t rotary_encoder_1_enc_b =  6;

        //ANO Rotary Encoder 2
        uint8_t rotary_encoder_2_left =   9;
        uint8_t rotary_encoder_2_up =     10;
        uint8_t rotary_encoder_2_right =  11;
        uint8_t rotary_encoder_2_down =   12;
        uint8_t rotary_encoder_2_center = 13;
        uint8_t rotary_encoder_2_enc_a =  15;
        uint8_t rotary_encoder_2_enc_b =  14;

        /**
         * Potentiometers
         */
        uint8_t POTENTIOMETER_1_ADC = 0;
        uint8_t POTENTIOMETER_2_ADC = 1;
        uint8_t POTENTIOMETER_3_ADC = 2;
        uint8_t POTENTIOMETER_4_ADC = 3;
        uint8_t POTENTIOMETER_5_ADC = 4;
        uint8_t POTENTIOMETER_6_ADC = 5;

        /**
         * Joysticks
         */
        uint8_t LEFT_JOYSTICK_X_1 =  0;
        uint8_t LEFT_JOYSTICK_X_2 =  1;

        uint8_t LEFT_JOYSTICK_Y_1 =  2;
        uint8_t LEFT_JOYSTICK_Y_2 =  3;

        uint8_t RIGHT_JOYSTICK_X_1 = 4;
        uint8_t RIGHT_JOYSTICK_X_2 = 5;

        uint8_t RIGHT_JOYSTICK_Y_1 = 6;
        uint8_t RIGHT_JOYSTICK_Y_2 = 7;

        // Joystick General
        uint8_t joystick_default_value;
        uint8_t joystick_min_out;
        uint8_t joystick_max_out;

        // Left Joystick
        uint8_t left_joystick_drift_value_x;
        int left_joystick_min_value_x;
        int left_joystick_max_value_x;
        int left_joystick_middle_value_x;

        uint8_t left_joystick_drift_value_y;
        int left_joystick_min_value_y;
        int left_joystick_max_value_y;
        int left_joystick_middle_value_y;

        // Right Joystick
        uint8_t right_joystick_drift_value_x;
        int right_joystick_min_value_x;
        int right_joystick_max_value_x;
        int right_joystick_middle_value_x;

        uint8_t right_joystick_drift_value_y;
        int right_joystick_min_value_y;
        int right_joystick_max_value_y;
        int right_joystick_middle_value_y;

        // Potentiometers
        uint8_t pot_drift_value;
        uint8_t pot_min;
        int pot_max;
        uint8_t pot_out_min;
        uint8_t pot_out_max;
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

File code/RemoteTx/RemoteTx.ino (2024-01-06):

/**
 * RC Transmitter – ESP32 / SX1280
 * https://github.com/alx-uta/RC-Transmitter
 * 
 * Alex Uta
 * microknot.dev
 */

// ESP32 specific files
#include "soc/timer_group_struct.h"
#include "soc/timer_group_reg.h"

// User Custom Config
#include "user_config.hpp"

// Libraries
#include <SPI.h>
#include <RadioLib.h>
#include <MCP_ADC.h>
#include <MCP23S17.h>

// Local files
#include "src/rotary/rotary.hpp"
#include "src/tx/tx.hpp"
#include "src/init.hpp"
#include "src/setup.hpp"

#if ENABLE_CALIBRATION
    #include "src/calibration.hpp"
#endif

/**
* We'll use core:0 for payload transmission
*/
void func_txTransmitData( void * pvParameters ){
    while(true){
        transmitData();
        feedTheDog();
    }
}

/**
 * We'll use core:1 to read 
 * the data from MCP3208 and MCP23S17T
 */
void func_txReadData( void * pvParameters ){
    while(true){
        /**
         * Read the data
         */
        _TX.readData();

        /**
         * Feed the dog
         */
        feedTheDog();
    }
}

void setup() {
    #if ENABLE_SERIAL_PRINT
        Serial.begin(115200);
    #endif

    /**
     * SX1280 setup
     */
    SX1280_setup();

    /**
     * MCP23S17T setup
     */
    MCP23S17T_setup();

    /**
     * MCP3208 Init
     */
    MCP3208_setup();

    #if ENABLE_CALIBRATION
        availableCalibrationOptions();
    #else
        xTaskCreatePinnedToCore(
            func_txReadData,
            "task_txReadData",
            100 * 1024,
            NULL,
            20,
            &task_txReadData,
            taskCore1
        );

        xTaskCreatePinnedToCore(
            func_txTransmitData,
            "task_txTransmitData",
            100 * 1024,
            NULL,
            19,
            &task_txTransmitData,
            taskCore2
        );
    #endif
}

void loop() {
  #if ENABLE_CALIBRATION
    calibrationCheckOption();
  #endif
}

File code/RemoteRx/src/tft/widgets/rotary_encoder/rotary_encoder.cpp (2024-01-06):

/**
 * RC Transmitter – ESP32 / SX1280
 * https://github.com/alx-uta/RC-Transmitter
 * 
 * Alex Uta
 * microknot.dev
 */

#include "rotary_encoder.hpp"

RotaryEncoder::RotaryEncoder(
    Config & config, 
    TFT_eSPI & tft,
    int x,
    int y
)
    :   _config(config),
        _tft(tft) {
            _x = x;
            _y = y;
        }

void RotaryEncoder::drawBigCircle() {
    _tft.drawCircle(_x, _y, RotaryEncoder::big_circle_radius, _config.TFT_ENCODER_BORDER_COLOUR);
}

void RotaryEncoder::drawSmallCircle(int x, int y, int state) {
    _border_colour = state ? _config.TFT_ENCODER_ACTIV_COLOUR : _config.TFT_ENCODER_BORDER_COLOUR;
    _fill_colour = state ? _config.TFT_ENCODER_ACTIV_COLOUR : _config.TFT_ENCODER_BORDER_COLOUR;

    _tft.drawCircle(x, y, RotaryEncoder::small_circle_radius, _border_colour);
    _tft.fillCircle(x, y, RotaryEncoder::small_circle_radius - 2, _fill_colour);
}

void RotaryEncoder::drawSmallCircles(
    int up,
    int down,
    int left,
    int right,
    int middle
) {
    drawSmallCircle(_x, _y - RotaryEncoder::big_circle_radius, up);
    drawSmallCircle(_x, _y + RotaryEncoder::big_circle_radius, down);
    drawSmallCircle(_x - RotaryEncoder::big_circle_radius, _y, left);
    drawSmallCircle(_x + RotaryEncoder::big_circle_radius, _y, right);
    drawSmallCircle(_x, _y, middle);
}

void RotaryEncoder::init(){
    RotaryEncoder::drawBigCircle();
    RotaryEncoder::update(
        0, 0, 0, 0, 0
    );
}

void RotaryEncoder::update(
        int up,
        int down,
        int left,
        int right,
        int middle
) {
    RotaryEncoder::drawSmallCircles(
        up,
        down,
        left,
        right,
        middle
    );
}

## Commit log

2024-01-06 RC Transmitter
    [18650_BatteryHolder.step, 18650_BatteryHolder.stl, 18650_BatteryHolderSpacer.step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]
2025-04-07 Directory Rename
    [RC_Transmitter_RX_FINAL_v4.4.brd, RC_Transmitter_RX_FINAL_v4.4.sch, RC_Transmitter_TX_FINAL_v4.4.brd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]

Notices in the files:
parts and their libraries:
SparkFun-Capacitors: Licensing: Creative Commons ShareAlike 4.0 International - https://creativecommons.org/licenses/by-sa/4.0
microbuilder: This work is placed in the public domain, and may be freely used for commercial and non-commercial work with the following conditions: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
